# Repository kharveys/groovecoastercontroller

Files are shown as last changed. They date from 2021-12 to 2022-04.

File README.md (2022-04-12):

# THIS GUIDE IS INCOMPLETE BUT SHOULD GIVE YOU A GENERAL DIRECTION

The original project was missing stuff that I wanted to see in a GC controller. I modified pretty much the whole design but the spacing is still correct. I also used an arduino for this to make it work on a Nintendo Switch (currently the only supported code) and made it so you can fully take it apart for maintenance for example. 

controller

---

# needed
- arduino pro micro
- a 3D printer
- a laser cutting machine
- 5mm acrylic
- 5mm MDF
- 9mm MDF
- 2 x chinese flight sticks
- 2 x 60mm buttons
- 2 screws for locking the top of the sticks (not manditory)
- Various bolts and nuts for securing the acrylic to the wood and the joy_base (will update later with amounts, just make sure to get long bolts for the spacers/joy_base)
- 6 x bumpon
- wood glue

# things to 3d print
- 2 x joy_stick.stl
- 2 x joy_base.stl
- 2 x joy_tube.stl

# things to laser cut
- Everything in the laser_cut_files folder (amount is specified)

# things of note
You will have to cut the flightstick shaft in other for it to fit is the joy_tube, cut it 2mm aboven the circular part (around where the red line is). You can remove the shaft by removing the ring that's on the underside.
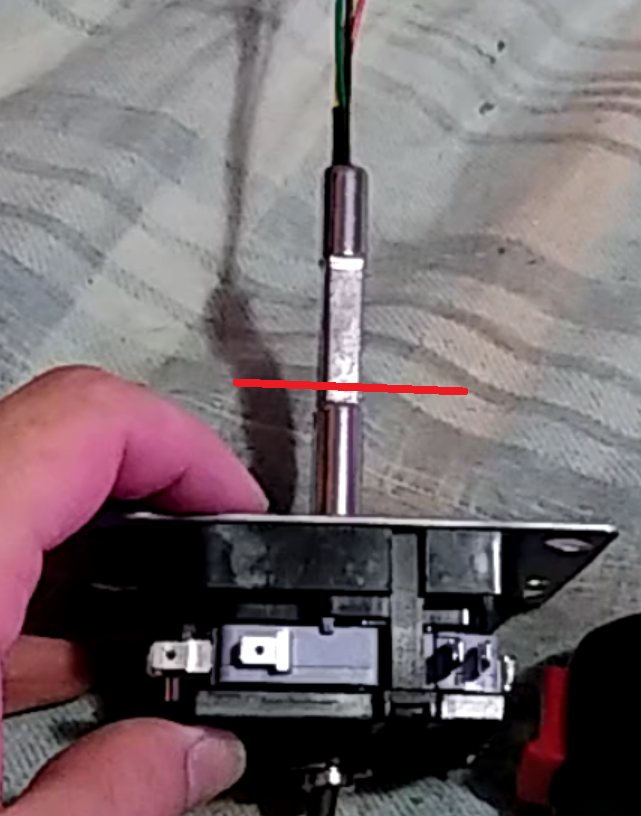
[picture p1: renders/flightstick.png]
flightstick


For the inside I added a picture I still had, not the best but should give you an idea of how it will look in the end. As you can see I used 2 spacers per side instead of 3. You can probably just try some stuff with other thicknesses and amounts.
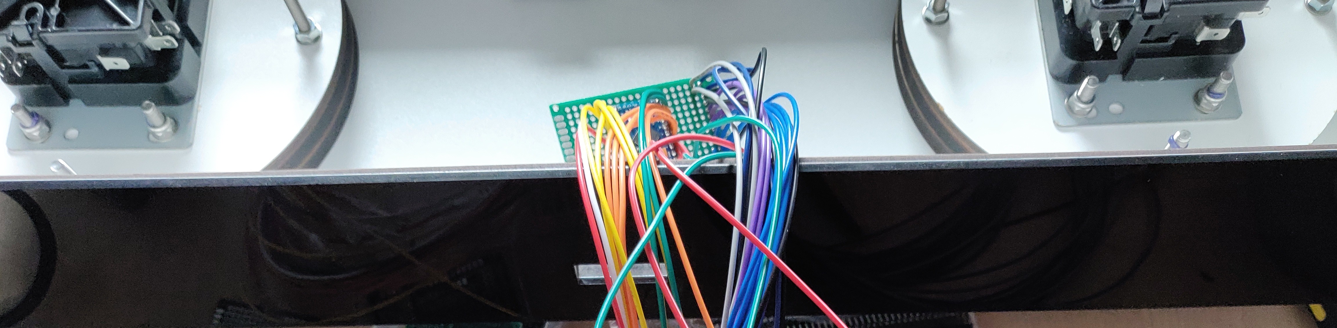
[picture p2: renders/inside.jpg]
inside


Twisting the joy_stick on is kind of hard with this setup, you should kinda put it in on an angle and then you'll be able to twist it in. You might have to screw around with the 60mm button orientation.

Feel free to ask me questions on discord: Harvey#7954

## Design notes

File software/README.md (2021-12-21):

Taken from https://github.com/knuckleslee/RhythmCodes/tree/master/2J3B3LED_gcjoy/leo under the GPL3 license.
Modified it for my use.

1.put boards.txt in C:\Program Files (x86)\Arduino\hardware\arduino\avr, backup the old one  
2.install this library https://github.com/celclow/SwitchControlLibrary/releases/tag/v1.0.0 (make sure it's v1.0.0)  
3.select board type: Leonardo Pokken  
4.upload code

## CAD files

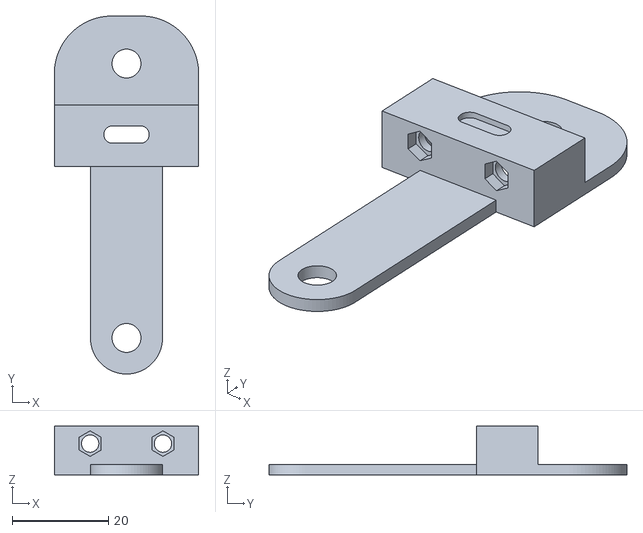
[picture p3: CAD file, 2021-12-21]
stl_files/usbc_assembly.STL
30.0 x 74.4 x 10.1

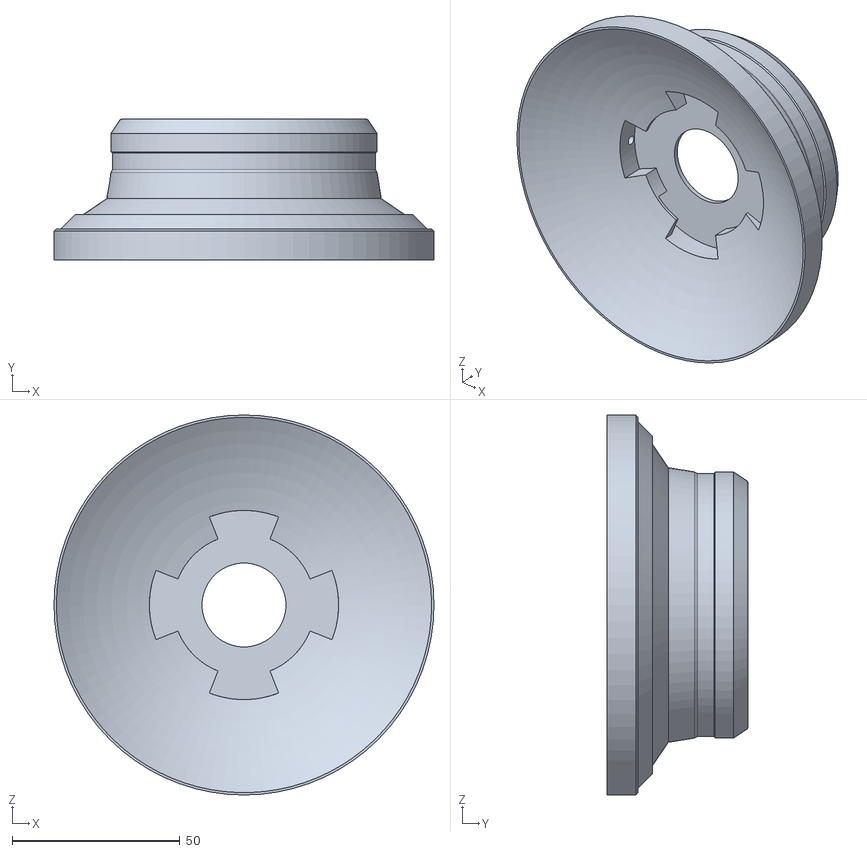
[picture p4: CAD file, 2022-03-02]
stl_files/joy_stick.STL
113.3 x 42.0 x 113.3

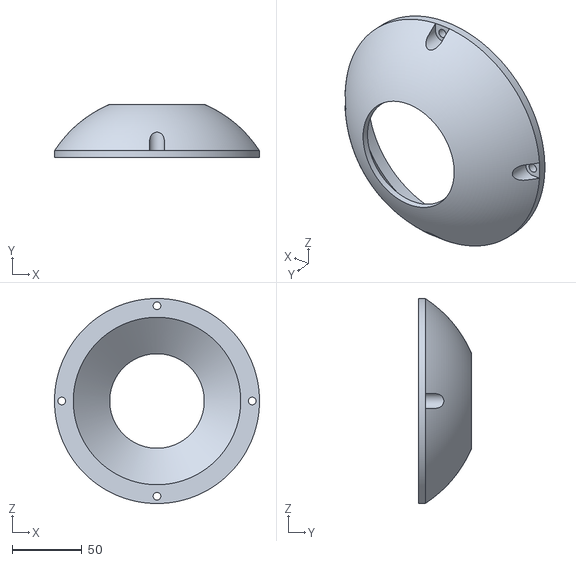
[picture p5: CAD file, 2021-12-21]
stl_files/joy_base.STL
146.7 x 37.7 x 146.7

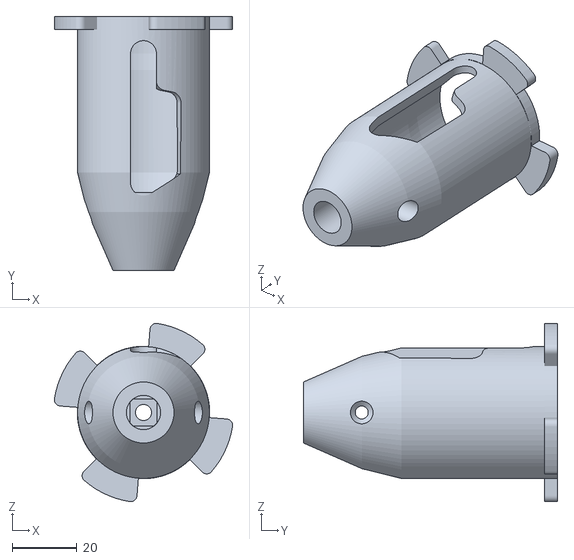
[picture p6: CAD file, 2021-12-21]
stl_files/joy_tube.STL
55.2 x 78.7 x 55.2

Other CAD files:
laser_cut_files/box_spacer_ring_6x.DWG
laser_cut_files/box_side_2x.DWG
laser_cut_files/acrylic_top.DWG
laser_cut_files/box_front_2x.DWG
laser_cut_files/box_bottom.DWG
laser_cut_files/box_top.DWG
laser_cut_files/box_middle_2x.DWG
laser_cut_files/acrylic_back_usb_hole.DWG
laser_cut_files/acrylic_front.DWG
laser_cut_files/acrylic_side_2x.DWG

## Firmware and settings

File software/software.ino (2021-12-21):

/* Arduino Groove Coaster Controller Code for Leonardo
 * 2 Joystick + 4 Buttons + 4 reactive LED
 * release page
 * http://knuckleslee.blogspot.com/2018/06/RhythmCodes.html
 * 
 * SwitchControlLibrary
 * https://github.com/celclow/SwitchControlLibrary
 */
#include <SwitchControlLibrary.h>

//          {  L,  R, Plus, Min, Lstick up, down, left, right, Rstick up(X), down(B), left(Y), right(A)};
int BT[]  = {  9,  8,   A0,  A1,         5,    4,    7,     6,           16,      10,      15,       14};
int LED[] = { A2, A3,    2,   3};
/* pin assignments
 * Joystick L up, down, left, right to pin 0, 2, 3, 1
 * Joystick R up, down, left, right to pin 4, 6, 7, 5
 * current pin layout
 *  LED[] = { 22, 18, 20} = LED 1 to 3
 *    connect pin to resistor and then + termnial of LED
 *    connect ground to - terminal of LED
 *  BT[]  = { 23, 19, 21} = Button input 1 to 3
 *    connect button pin to ground to trigger button press
 * Virtual 3rd button:
 *  hold L+R button for 5 second to press 3rd(plus) button
 */
const byte DigitalStick = 100;  //Input value for emulated analog stick
const byte ButtonCount = sizeof(BT) / sizeof(BT[0]);
const byte LedCount = sizeof(LED) / sizeof(LED[0]);
byte LeftStickX = 128;  //centered analog
byte LeftStickY = 128;  //centered analog
boolean KeyStatus[2*ButtonCount] = {0};

const int T_VButtonPlus = 5000;  //Threshold of Virtual ButtonPlus (millis)
unsigned long B_VButtonPlus[2] = {0};  //Timing buffers of Virtual ButtonPlus
unsigned long ReportRate;
int ReportDelay = 700;

void setup() {
  Serial.begin(9600);
  for (int i = 0; i < ButtonCount; i++) 
  pinMode(BT[i], INPUT_PULLUP);
  
  for (int i = 0; i < LedCount; i++) 
  pinMode(LED[i],OUTPUT);
}

void loop() {
  ReportRate = micros() ;

  for (int i = 0; i < ButtonCount; i++) {
    KeyStatus[i] = digitalRead(BT[i]);  //read status
  }
  if(KeyStatus[0] != KeyStatus[0+ButtonCount]) {
    if(KeyStatus[0] == LOW )
      { SwitchControlLibrary().PressButtonL();  }
    else
      { SwitchControlLibrary().ReleaseButtonL();  }
  }
  if(KeyStatus[1] != KeyStatus[1+ButtonCount]) {
    if(KeyStatus[1] == LOW )
      { SwitchControlLibrary().PressButtonR();  }
    else
      { SwitchControlLibrary().ReleaseButtonR();  }
  }

  if(KeyStatus[2] != KeyStatus[2+ButtonCount]) {
    if(KeyStatus[2] == LOW )
      { SwitchControlLibrary().PressButtonPlus();  }
    else
      { SwitchControlLibrary().ReleaseButtonPlus();  }
  }
  
  if(KeyStatus[3] != KeyStatus[3+ButtonCount]) {
    if(KeyStatus[3] == LOW )
      { SwitchControlLibrary().PressButtonMinus();  }
    else
      { SwitchControlLibrary().ReleaseButtonMinus();  }
  }
//initialize LeftStick
  if(KeyStatus[4] != KeyStatus[4+ButtonCount]) {
    if(KeyStatus[4] == LOW)
      {LeftStickY = LeftStickY-DigitalStick;  }
    else
      {LeftStickY = LeftStickY+DigitalStick;  }
  }
  
  if(KeyStatus[5] != KeyStatus[5+ButtonCount]) {
    if(KeyStatus[5] == LOW)
      {LeftStickY = LeftStickY+DigitalStick;  }
    else
      {LeftStickY = LeftStickY-DigitalStick;  }
  }

  if(KeyStatus[6] != KeyStatus[6+ButtonCount]) {
    if(KeyStatus[6] == LOW)
      {LeftStickX = LeftStickX-DigitalStick;  }
    else
      {LeftStickX = LeftStickX+DigitalStick;  }
  }

  if(KeyStatus[7] != KeyStatus[7+ButtonCount]) {
    if(KeyStatus[7] == LOW)
      {LeftStickX = LeftStickX+DigitalStick;  }
    else
      {LeftStickX = LeftStickX-DigitalStick;  }
  }

  SwitchControlLibrary().MoveLeftStick(LeftStickX, LeftStickY);

//
  if(KeyStatus[8] != KeyStatus[8+ButtonCount]) {
    if(KeyStatus[8] == LOW )
      { SwitchControlLibrary().PressButtonX();  }
    else
      { SwitchControlLibrary().ReleaseButtonX();  }
  }
  if(KeyStatus[9] != KeyStatus[9+ButtonCount]) {
    if(KeyStatus[9] == LOW )
      { SwitchControlLibrary().PressButtonB();  }
    else
      { SwitchControlLibrary().ReleaseButtonB();  }
  }
  if(KeyStatus[10] != KeyStatus[10+ButtonCount]) {
    if(KeyStatus[10] == LOW )
      { SwitchControlLibrary().PressButtonY();  }
    else
      { SwitchControlLibrary().ReleaseButtonY();  }
  }
  if(KeyStatus[11] != KeyStatus[11+ButtonCount]) {
    if(KeyStatus[11] == LOW )
      { SwitchControlLibrary().PressButtonA();  }
    else
      { SwitchControlLibrary().ReleaseButtonA();  }
  }

  for (int i = 0; i < ButtonCount; i++) {
    KeyStatus[i+ButtonCount] = KeyStatus[i];  //save status
  }

  for (int i = 0; i < LedCount; i++) {
    for (int i = 0; i < 2; i++) {
      if(digitalRead(BT[i])==LOW) {
      digitalWrite(LED[i],LOW);
      } else {
      digitalWrite(LED[i],HIGH);
      }
    }
    for (int i = 2; i < LedCount; i++) {
      if(digitalRead(BT[i])==LOW) {
      digitalWrite(LED[i],HIGH);
      } else {
      digitalWrite(LED[i],LOW);
      }
    }
  }

  //delayMicroseconds(ReportDelay);
  //ReportRate Display
  //Serial.print(micros() - ReportRate) ;
  //Serial.println(" micro sec per loop") ;
}  //end loop

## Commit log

2021-12-21 Initial changes to the repository
    [acrylic_back_usb_hole.DWG, acrylic_front.DWG, acrylic_side_2x.DWG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]
2022-03-02 design change to old version
    [joy_stick.STL]
